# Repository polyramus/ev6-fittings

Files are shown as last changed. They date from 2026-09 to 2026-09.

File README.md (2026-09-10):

# ev6-fittings

*Ordning och reda* for the Kia EV6 — Swedish for “order and tidiness,” which is
the entire product line in one phrase.

3D-printed interior utility parts, one at a time. Each item fixes a small,
daily friction in the car that no official accessory covers. One subdirectory
per item; measured source data (STLs, photos) lives in `data/`.

## Items

### Cup-holder inlay (`cup-holder-inlay/`)

Drops into the center console cup holders:

- kills the rattle from the factory holder springs
- gives slim bottles a snug, non-rocking fit

### Planned

- Miniature trash can for the lower tray
- Replacement fuse box lid with an OBD-shaped opening

## Print notes

(to be filled in per item: printer, resin/PLA, orientation, supports)

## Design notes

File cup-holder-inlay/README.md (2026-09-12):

# Cup-holder inlay

Parametric OpenSCAD inlay for the EV6 centre-console cup area: immobilises the
four factory spring tabs (the rattle source) and adds a rattle-free grip for a
58 mm thermos or a 66 mm 0.5 l PET bottle in the front pocket.

## Files

- `ev6_cup_inlay.scad` — grip parameters, render switches, assembly, fit report
- `lib_geometry.scad` — all dimensional parameters + the three-tray envelope,
  conical front pocket, inlay shell, slanted console top
- `lib_parts.scad` — arc leaf-spring grip, factory-tab traps, test cups
- `aframe.scad` — the A-frame divider (see below), standalone part
- `lib_aframe.scad` — the A-frame divider: parameters + geometry, shared by
  `aframe.scad` (standalone) and the inlay assembly (fitted test object)
- `../data/` — the source data: `EV6 Utility Cup.stl`, `IMG_5344` (mat on a
  14" MBP, top view), `IMG_5345` (front pocket with the factory tabs),
  `IMG_5346` (console slant), `IMG_5347`/`IMG_5348` (mat + A-frame divider),
  `IMG_5349` (console from the passenger side; the driver-side A-stud),
  `IMG_5350` (mat + clamp on the floor, side view)

## Dimension provenance (2026-09-09, updated 2026-09-12)

- **Front pocket — precise (lower 62.5 mm).** `data/EV6 Utility Cup.stl`
  (Thingiverse, "EV6 Utility Cup (Precision Fit)") is a *negative* of the
  front cavity: conical, Ø75.07 at the seating level → Ø82.46 at its top,
  62.5 mm tall (walls lean out 3.7 mm/side). The part seats on the TPU mat.
  The pocket itself is taller (~79 mm from the mat to the console top — see
  the slant below), so the model continues the measured lean above the cone
  (`r_pocket`); the extra ~17 mm of wall is an assumption, flagged there.
- **Console top — slanted.** Caliper to the molded floor: 82 mm at the front,
  ~75 at the back; the TPU mat under the front pocket is ~3 mm, so the front
  pocket is ~79 from its floor (`H_FRONT_MAT`; if the caliper rested on the
  mat, set it to 82). With level floors (assumed) the top is one plane
  through (y=0, z=87) and (y=300.6, z=75) — `H_top(y)`, ~2.3°, falling to
  the rear. Everything is trimmed with `slant_cutter()`, so the inlay top is
  flush with the console top along the whole slant.
- **Rear footprint — photo.** `data/IMG_5344.jpg`: top view of the car's soft
  TPU mat on a 14" MacBook Pro (221.3 mm short side as scale). Total length
  298.9 mm, 24 mm passage, tab-notch pairs at both step corners, the 20×9 mm
  passenger-side bridge, and the long asymmetric tray-3 taper to a ~12 mm
  passenger tip (the LHD chamfer — the RHD variant is its mirror).
- **A-frame side profile + tenons — photo (2026-09-12).** `IMG_5350` (clamp
  side view) gives the asymmetric sawbuck contour; `IMG_5349` (console from
  the passenger side) gives the A-shaped floor tenons. The apex offset,
  dome radius, and tenon front-slant are read off the soft photo — caliper
  to confirm (see the A-frame section's assumed list).
- **Everything else** calipered by the owner. "width" = X (transverse),
  "length" = Y (fore-aft).

## Render

```sh
openscad -o inlay.png   -D 'TEST_CUP="none"'    ev6_cup_inlay.scad
openscad -o thermos.png -D 'TEST_CUP="thermos"' ev6_cup_inlay.scad
openscad -o pet.png     -D 'TEST_CUP="pet"'     ev6_cup_inlay.scad
```

`TEST_CUP` drops a translucent test cup into the front pocket and renders the
grip mechanism engaged against it. The compile-time `echo` report prints
pocket ID at seat/grip height, per-cup deflection, and the max arm strain.

## The factory-tab traps (measured 2026-09-10)

The four factory tabs are spring flaps 7.5 wide x 30 tall in wall openings:
pivot near the top, ~14 mm of free-end travel, folding fully into the wall
when pressed (which is exactly how the owner keeps them quiet). All four sit
~30 mm above their tray floor — the tray-2 pair level with the front pair.
(The white lines in photo `IMG_5345` are duct-tape residue from earlier
makeshift fastening, not damage.)

- **Front pocket** — two tabs ~45 deg each side of the passage (photo
  `IMG_5345`), on the cone. Traps are **flush-press bosses**: a tapered
  plate following the cone, its face 0.2 mm in front of the console wall
  face. The flap is trapped behind the inlay wall, so the face alone limits
  its bulge to 0.2 mm instead of 14 mm — no channel needed.
- **Tray 2** — two identical tabs at the tray-2/3 boundary (the mat notch
  pair, ~6 mm in from each wall, x = ±31.5), flaps tilted 45 deg toward each
  other — an X seen from above. No feature needed: the inlay's offset wall
  band runs full height over those faces, so the band's own face (0.15 mm
  in front of the car face) is the flush-press limiter. (First described
  against the 51-narrowing "step," since corrected to full width — re-confirm
  the exact face.)

Insertion: press all four tabs in, drop the inlay, and they stay
immobilised.

## The grip mechanism

Three arc-segment leaf-spring tabs (passenger, driver, front; the rear
quadrant is left clear for the trapped factory tabs). Each arm is an annular
sector following the pocket curvature, so nothing pokes through the circular
wall. The pad is printed 0.3 mm past its stop face, so in the car the arm is
pre-stressed and the pad is always pressed home — zero free play, and a hard
stop at the other end of travel (the cup), so it cannot rattle. PET
engagement bends the 1.2 mm arm ~4.6 mm over a 20 mm lever (~2 % strain —
at the low end of PLA/PETG yield).

## Print notes

- FDM, 0.2 mm layers, PETG preferred (arm flex + car heat).
- Print as-is (open top up): walls are vertical or leaning out, no supports
  needed; the grip pad bridges ~4 mm above the pocket floor (`GRIP_Z0`).
  The top rim is a slanted plane (the console slant) — cosmetic only.
- `TOL = 0.15` per side vs the car; drop to 0.1 if the fit feels loose.

## TODO — measurements still needed

Photo-derived values are soft-mat estimates (±3 mm); caliper to confirm:

- `H_FRONT_MAT` (79) — is the 82 mm caliper read to the molded floor (as
  assumed, minus the ~3 mm mat) or to the mat itself (then 82)? Also the
  ~17 mm of front-pocket wall above the measured STL cone assumes the lean
  continues — confirm the pocket's true top radius.
- `L_T2_CONN` (24), `L_T3_END_L` (50) / `L_T3_END_R` (20), `TIP_W` (12),
  `R_T3_CORNER` (6) — the rear end from the photo
- `BRIDGE_RELIEF` (1) — confirm the car's passage-1 bridge is flush with the
  mat top; set 0 if it sits below
- `GRIP_Z0` — land the grip band on the actual bottle's 66 mm body band
  (the test PET's 18 mm flare is a placeholder; measure the real bottle)
- The inlay seats on the TPU mat; if the mat compresses under the front
  section, the seat height shifts — verify in the car. The mat also has
  slightly raised sides extending ~1 mm past the base.

## The A-frame divider (`aframe.scad`)

The car's detachable A-frame divider, at the **tray-2 / tray-3 boundary**
in the rear console (not the front pocket). Its job is to stop the rattle
from the three loose plastic layers on the passenger-side console wall: the
inlay-fit variant below drops inside the printed inlay and cams that wall
ever so slightly outward on insertion, tensioning the cover. The factory
part is injection molded, but the shape prints fine in FDM.

**Shape (side profile, `IMG_5350`).** A **solid sawbuck** — an extruded "A"
with the counter filled, so the section is a solid triangle. It is
**asymmetric**, not a symmetric triangle: a long front slant, a short
near-vertical back, the apex offset toward the rear (~62% of the base,
`AFRAME_APEX_Y`), and a rounded top (`AFRAME_TOP_R`). 74 wide in X
(`AFR_CLAMP_W` — the tray walls are "almost 8 cm"), 45 deep in Y (the base),
61 tall in Z.

**The floor tenons (`IMG_5349`).** Two **A-shaped studs** rise ~1 cm from
the molded floor at the passage, one on each side (`AFR_STUD_*` in
`lib_geometry`): X-constant 11.75 wide, Y 34 → 30, the front face slanted
parallel to the frame's front slant and the back near-vertical. The frame
rests on their tops with the central passage left open (`AFR_PASSAGE_W`
= 50.5) — the "1 cm open area beneath the A-frame." No flange or latch; the
parallel front faces locate the frame. The tenons run from the passage all
the way to the console-well wall, so the inlay carries a matching
**A-shaped cutout** for each — through the floor *and* the side wall it
butts against (`aframe_stud_cutout` in `lib_aframe`).

**Bottle cutout.** A ~75 mm circle on one side (`CUTOUT_*`) so a bottle in
tray 2 sits in front of the frame; only its back crescent bites a ~45 mm
dent into the front slant.

**Two fits** (`AFRAME_FIT`; widths from `aframe_w`):
- **`"car"`** — the factory-style part: 74 wide, resting on the car's floor
  tenons (z = `AFR_STUD_H`), press-fitting the bare tray.
- **`"inlay"`** — the new divider: inset `AFR_INSET` (4) each side → 66
  wide, so it drops inside the inlay's rear void and cams the wall outward.
  Rendered in `ev6_cup_inlay.scad` with `SHOW_AFRAME=true`.

**Assumed, not measured** (flagged in the `lib_aframe.scad` header — verify
in the car): the frame's Y position (`AFRAME_Y0`), the apex offset + dome
radius (`AFRAME_APEX_Y` / `AFRAME_TOP_R`, read off the soft photo), the
bottle-cutout side/height/depth, and the tenon front-slant ratio.

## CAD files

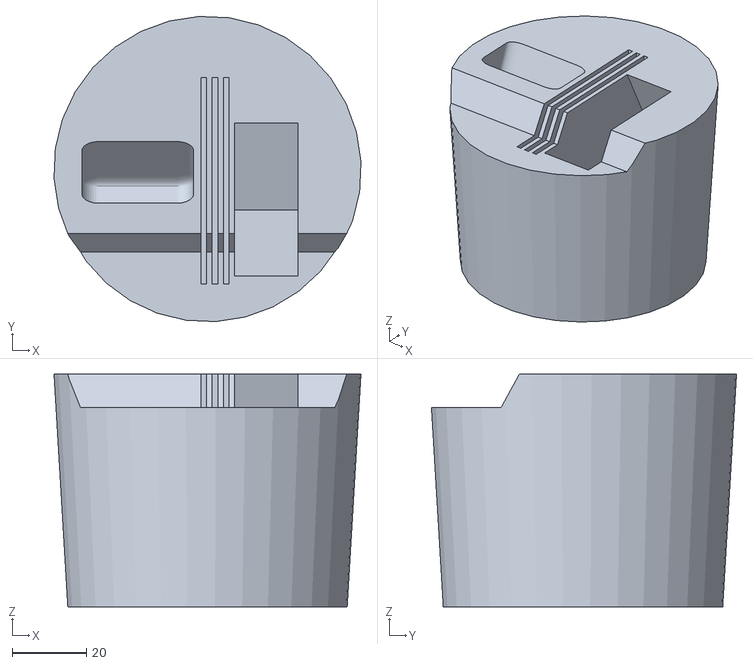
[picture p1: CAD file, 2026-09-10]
data/EV6 Utility Cup.stl
82.5 x 82.0 x 62.5

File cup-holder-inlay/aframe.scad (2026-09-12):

// aframe.scad — ev6-fittings / cup-holder-inlay
// Standalone preview of the A-frame divider. The geometry lives in
// lib_aframe.scad (shared with ev6_cup_inlay.scad, where the same frame also
// renders as a fitted test object inside the inlay); this file only picks a
// fit and renders it.
//
// The A-frame is a SOLID ASYMMETRIC SAWBUCK (an extruded "A" with the counter
// filled — long front slant, near-vertical back, apex toward the rear,
// rounded top): 74 wide in X (AFR_CLAMP_W, spans the tray), 45 deep in Y
// (the base), 61 tall in Z. It stands at the tray-2/tray-3 boundary on two
// A-shaped floor tenons; a circular cutout on one side lets a bottle sit in
// tray 2. See lib_aframe for the dimensions and the ASSUMED list (verify in
// the car).
//
// Fit (AFRAME_FIT):
//   "car"   — the factory-style part: 74 wide, resting on the car's floor
//             tenons (z = AFR_STUD_H), press-fitting the bare car tray.
//   "inlay" — the NEW slightly-smaller divider: fits inside the printed
//             inlay's tray-2/3 void and pushes the inlay wall outward to
//             strain the console.
//
// Render:
//   openscad -o aframe.png        aframe.scad                 // inlay fit, inlay shown
//   openscad -o aframe_car.png    -D 'AFRAME_FIT="car"' -D 'SHOW_INLAY=false' aframe.scad
//   (add -D 'SHOW_POCKET=true' to ghost the car cavity)

$fn = 96;
include <lib_geometry.scad>   // TOL, WALL, inlay_shell, cavity, tray-2/3 Y layout
include <lib_aframe.scad>     // aframe(fit), aframe_solid, aframe_z0

AFRAME_FIT   = "inlay";   // "car" | "inlay"
SHOW_POCKET  = false;     // ghost the car cavity
SHOW_INLAY   = true;      // the printed inlay the "inlay" fit lives inside

if (SHOW_POCKET)
    color("gray", 0.25) cavity();
if (SHOW_INLAY)
    color("#d8d8d0", 0.35) inlay_shell();
color("#b0b0a8") aframe(AFRAME_FIT);

echo("aframe (", AFRAME_FIT, "): ", aframe_w(AFRAME_FIT), " x 61 x 45 sawbuck, y0 ", AFRAME_Y0,
     ", z0 ", aframe_z0(AFRAME_FIT));

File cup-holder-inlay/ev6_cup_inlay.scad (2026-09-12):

// ev6_cup_inlay.scad — ev6-fittings
// Parametric inlay for the Kia EV6 centre-console cup area (3 interconnected
// trays). Goals:
//   1. immobilise the four factory spring tabs (rattle source)
//   2. rattle-free grip for 58 mm thermos ... 66 mm 0.5 l PET in the front
//      pocket (leaf-spring tabs, both travel ends hard-stopped)
//   3. fill/flatten the remaining two trays
//
// OpenSCAD >= 2021.  Render the three fits:
//   openscad -o inlay.png      -D 'TEST_CUP="none"'    ev6_cup_inlay.scad
//   openscad -o thermos.png    -D 'TEST_CUP="thermos"' ev6_cup_inlay.scad
//   openscad -o pet.png        -D 'TEST_CUP="pet"'     ev6_cup_inlay.scad
//   openscad -o aframe_fit.png -D 'TEST_CUP="none"' -D 'SHOW_AFRAME=true' \
//                              ev6_cup_inlay.scad      // A-frame clamp in the inlay
//   (add -D 'SHOW_ENVELOPE=true' to ghost the car cavity around the inlay)
//
// Dimension provenance lives with the dimensions, in lib_geometry.scad
// (STL + top-view photo, 2026-09-09). This file keeps the grip mechanism
// parameters, the render switches, the assembly and the fit report.
//
// Coordinate system: X transverse, +X = driver side (LHD), -X = passenger;
// Y fore-aft, +Y toward the rear trays; z=0 = lower (rear) tray floor,
// z=LIFT = front pocket floor, z=H_top(y) = slanted console top.

// ================= grip mechanism =================
// Arc-segment leaf-spring tabs (see lib_parts.scad): the arm is an annular
// sector following the pocket curvature, so every feature stays inside the
// pocket; deflection is an exact rotation about the pocket centre.
CUP_MIN_D  = 58.0;   // thermos
CUP_MAX_D  = 66.0;   // 0.5 l PET body (EU standard max)
GRIP_TAB_ANG = [0, 180, 270];  // rear quadrant left clear for factory tabs
GRIP_SPAN    = 36.0;   // arm arc span (deg); lever ~ r * span = 20 mm
GRIP_ARM_R0  = 32.0;   // arm inner radius (centreline 32.6)
GRIP_ARM_T   = 1.2;    // arm radial thickness = bending direction
PRELOAD      = 0.3;    // print the pad 0.3 mm PAST the stop face: in the car
                       // the stop blocks it, so the arm is pre-stressed and
                       // the pad is always pressed home -> zero free play
GRIP_Z0      = 4.0;    // TODO: grip band bottom above pocket floor; keep the
GRIP_Z_H     = 10.0;   // pad's bottom bridge short (FDM), land on the PET
                       // 66 mm body band

// ================= render switches =================
TEST_CUP      = "thermos";  // "none" | "thermos" | "pet"
SHOW_ENVELOPE = false;
// A-frame divider fitted inside the inlay's rear (tray-2/3) void (the "inlay"
// fit from lib_aframe — the slightly-smaller clamp that cams the wall out).
// Render it alone (TEST_CUP="none"): the inlay goes translucent so the frame
// inside the rear void reads.
SHOW_AFRAME   = false;

// High-poly circles (kit convention, cf. motor-bench/cad/params.scad): the
// 74 mm pocket circle runs through offset() and CSG booleans.
$fn = 96;

include <lib_geometry.scad>
include <lib_parts.scad>
include <lib_aframe.scad>   // the A-frame divider, rendered as a fitted test object

// ================= assembly =================
// defl: render the grip arms deflected outward from the printed (empty)
// state -- 0 for a bare inlay, cup_deflection(d) to show a cup engaged.
module inlay(defl = 0) {
    union() {
        inlay_shell();
        grip_tabs(defl);
        factory_tab_bosses();   // flush-press bosses; no channels — the
                                // flaps fold behind the inlay wall (lib_parts)
    }
}

module assembly() {
    defl = TEST_CUP == "pet" ? cup_deflection(CUP_MAX_D)
           : TEST_CUP == "thermos" ? cup_deflection(CUP_MIN_D)
           : 0;
    if (SHOW_ENVELOPE) cavity_ghost();
    // Translucent inlay while the A-frame test object is inside, so the
    // band-vs-wall fit reads; the cup renders stay opaque.
    color("#b8b8b0", SHOW_AFRAME ? 0.3 : 1.0) inlay(defl);
    if (TEST_CUP != "none") test_cups();
    if (SHOW_AFRAME) color("#8a8a80") aframe("inlay");
}

assembly();

// ================= clearance / fit report =================
echo("console top: front = ", H_TOP_FRONT, " mm, rear = ", H_top(Y_T3_REAR),
     " mm, slant = ", SLANT_ANG, " deg");
echo("front pocket ID @ seat = ", 2 * (R_T1_BOT - TOL - WALL),
     " mm (STL cavity 75.07)");
echo("front pocket ID @ top  = ", 2 * (r_pocket(H_TOP_FRONT) - TOL - WALL),
     " mm (lean continued past the STL cone, see H_FRONT_MAT)");
echo("front pocket ID @ grip = ", 2 * R_PKT_GRIP, " mm (z = ", GRIP_ZC, ")");
echo("thermos radial play    = ", R_PKT_GRIP - CUP_MIN_D / 2,
     " mm/side at the grip band (closed by the pads)");
echo("PET body radial play   = ", R_PKT_GRIP - CUP_MAX_D / 2,
     " mm/side at the grip band (closed by the pads)");
echo("pad face: printed/seated = ", PAD_PRINT_R, " / ", PAD_STOP_R, " mm");
echo("thermos arm deflection = ", cup_deflection(CUP_MIN_D), " mm over L=", GRIP_LEVER);
echo("PET arm deflection     = ", cup_deflection(CUP_MAX_D), " mm over L=", GRIP_LEVER);
echo("max arm strain ~       = ", 3 * cup_deflection(CUP_MAX_D) * GRIP_ARM_T / (2 * GRIP_LEVER^2),
     " (yield ~0.02-0.05 for PLA/PETG)");
echo("total footprint length = ", Y_T3_REAR,
     " mm (front edge to passenger tip; photo read 298.9)");

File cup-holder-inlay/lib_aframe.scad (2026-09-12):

// lib_aframe.scad — ev6-fittings / cup-holder-inlay
// The A-frame divider: parameters + geometry, shared by the standalone
// preview (aframe.scad) and the inlay assembly (ev6_cup_inlay.scad, where
// it renders as a fitted test object).
//
// What it is (user 2026-09-10; contour from IMG_5350, tenons from IMG_5349,
// 2026-09-12): a SOLID SAWBUCK — an extruded "A" with the counter filled, so
// the section is a solid ASYMMETRIC triangle (long front slant, short
// near-vertical back, apex offset toward the rear, rounded top — see
// aframe_section). It stands at the tray-2/tray-3 boundary in the rear
// console: 74 wide in X (AFR_CLAMP_W, spans the tray), 45 deep in Y (the
// base), 61 tall in Z. A circular cutout on one side lets a bottle sit in
// tray 2. It rests on two A-shaped floor tenons (aframe_tenons). The factory
// part is injection molded; the shape prints fine in FDM.
//
// Requires lib_geometry.scad to be included first (TOL, WALL, and the
// tray-2/3 Y layout: Y_T2_REAR, Y_P2_REAR). No top-level instantiation here.
//
// ================= ASSUMED — verify in the car =================
//   AFRAME_Y0  — where it sits in Y. Set to the tray-2/3 boundary (Y_T2_REAR,
//                y~188). The 45 base then runs from there toward tray 3.
//                Confirm the exact position in the car.
//   AFRAME_APEX_Y / AFRAME_TOP_R — apex offset toward the rear + rounded-top
//                radius, read off IMG_5350 (a soft, angled photo). Caliper.
//   CUTOUT_*   — the ~75 mm bottle circle: placed in front (toward tray 2),
//                centred on x=0, so only its back crescent bites a ~45 mm-wide,
//                9-10 mm-deep dent into the front slant. Confirm which side it
//                is actually on and the exact height/depth in the car.
// ================================================================

// ---- envelope (measured 2026-09-10) ----
AFRAME_BASE = 45.0;   // base depth (Y), the "45 at the base"
AFRAME_H    = 61.0;   // total height (Z), the "~6 cm tall"
// Side profile (IMG_5350): ASYMMETRIC. A long front slant, a short near-
// vertical back, apex offset toward the rear, rounded top. APEX_Y is the
// apex's offset from the front edge along the base (middle = BASE/2).
AFRAME_APEX_Y = 28.0;    // apex toward the back (~62% of the base)
AFRAME_TOP_R  = 6.0;     // rounded-top radius
// (width is aframe_w(fit) -> AFR_CLAMP_W = 74, the clamp spanning the ~79
//  tray; user 2026-09-10: "the walls are always at almost 8 cm".)
// The A-frame sits at the tray-2/3 boundary (y 188..225 in lib_geometry);
// its 45 base spans that region. Two floor tenons protrude here and the frame
// rests on them (see aframe_tenons). The base is raised AFR_STUD_H above the
// floor, leaving the passage open in the middle.
AFRAME_Y0   = 184.0;  // 45 base centred on passage 2 (188..225), bridging it

// ---- bottle cutout (user 2026-09-10) ----
// A ~75 mm circle (a bottle sitting in tray 2) that only CLIPS the front of
// the frame: its back crescent bites a ~45 mm-wide, 9-10 mm-deep dent into the
// front slant. It is NOT a through-hole -- the circle mostly sits in tray 2.
CUTOUT_D  = 75.0;         // the bottle circle diameter (user "~75 mm")
CUTOUT_CY = AFRAME_Y0 - 28.0;  // ASSUMED circle centre (x=0, in front of the
                               // base edge): 37.5-28 = 9.5 mm of crescent bites
                               // in (~45-50 mm wide). Confirm side + position.

// ---- fit ----
// "car":   the factory part — AFR_CLAMP_W (74) wide, press-fitting the bare
//          car tray; rests on the car's floor tenons (z = AFR_STUD_H).
// "inlay": the NEW divider — inset AFR_INSET each side so it fits inside the
//          inlay's rear void and cams the wall outward on insertion. The inlay
//          void is the car footprint (75->71) offset in by WALL+TOL, ~67-71.
// Both rest ON the two A-shaped floor tenons: the base sits at the tenon tops,
// AFR_STUD_H above the car floor, in EITHER fit (the tenons rise from the car
// floor to z=AFR_STUD_H whether or not the inlay is present — through the
// inlay floor for the inlay fit). The ~1 cm void beneath is open in the
// middle (the passage), tenons on the sides.
AFR_INSET = 4.0;   // inlay-fit inset each side (fits the inlay rear void,
                   // tightest at the tray-3 side ~66.5 mm)
function aframe_w(fit) = fit == "inlay" ? AFR_CLAMP_W - 2 * AFR_INSET : AFR_CLAMP_W;
function aframe_z0(fit) = AFR_STUD_H;

// Solid-sawbuck section as a 2D profile (local x = height/Z, local y = Y):
// an ASYMMETRIC triangle (IMG_5350) — front-base [0,0], back-base [0,BASE],
// apex toward the rear at [h-R, APEX_Y] — with a rounded top: the hull of the
// triangle and a TOP_R circle at the apex gives straight slants + a dome.
module aframe_section(h) {
    hull() {
        polygon(points = [
            [0, 0],
            [0, AFRAME_BASE],
            [h - AFRAME_TOP_R, AFRAME_APEX_Y],
        ]);
        translate([h - AFRAME_TOP_R, AFRAME_APEX_Y])
            circle(d = 2 * AFRAME_TOP_R);
    }
}

// The solid sawbuck, aframe_w(fit) across (X). Rotate -90 about Y maps local
// z -> global -x and local x -> global z, so the extrude runs -X: origin at
// +w/2, base at AFRAME_Y0, floor at aframe_z0(fit).
module aframe_solid(fit) {
    w = aframe_w(fit);
    translate([w / 2, AFRAME_Y0, aframe_z0(fit)])
        rotate([0, -90, 0])
            linear_extrude(w) aframe_section(AFRAME_H);
}

module aframe(fit = "car") {
    difference() {
        aframe_solid(fit);
        // the bottle dent: a 75 mm vertical cylinder centred in front of the
        // base edge (toward tray 2) -- only its back crescent removes material
        translate([0, CUTOUT_CY, aframe_z0(fit) - 1])
            cylinder(h = AFRAME_H + 2, d = CUTOUT_D);
    }
}

// ---- floor tenons (the CAR feature the frame drops onto) ----
// Two A-shaped tenons at the passage (lib_geometry AFR_STUD_*): X width
// constant, ~1 cm tall, Y-footprint AFR_STUD_L_BASE at the floor narrowing to
// AFR_STUD_L_TOP at the top. The FRONT face slants back parallel to the frame's
// front slant (the "slant that matches the inside of the a-frame", IMG_5349)
// and the back face is near-vertical — so each tenon is a small positive "A".
// No flange/latch — the clamp rests on the tops and the parallel front faces
// locate it. Rendered as reference car geometry (aframe.scad), NOT part of the
// printable frame.
module aframe_stud_section() {
    // 2D profile (local x = height/Z, local y = Y-depth, front = 0). Base
    // L_BASE (front y=0 .. back y=L_BASE), front face slants back to L_TOP at
    // the top, back face vertical.
    polygon(points = [
        [0, 0],                                       // front-bottom
        [0, AFR_STUD_L_BASE],                         // back-bottom
        [AFR_STUD_H, AFR_STUD_L_BASE],                // back-top (back vertical)
        [AFR_STUD_H, AFR_STUD_L_BASE - AFR_STUD_L_TOP], // front-top (front slant)
    ]);
}
module aframe_tenon(sx) {
    cx = sx * AFR_STUD_X;
    translate([cx + AFR_STUD_W / 2, AFR_STUD_Y - AFR_STUD_L_BASE / 2, 0])
        rotate([0, -90, 0])
            linear_extrude(AFR_STUD_W) aframe_stud_section();
}
module aframe_tenons() {
    aframe_tenon(-1);
    aframe_tenon(1);
}

// A-shaped clearance cutout for one floor tenon, subtracted from the inlay
// (lib_geometry.inlay_shell). The tenons run from the passage ALL THE WAY to
// the console-well wall, so the cutout is the tenon's A-profile offset out by
// TOL, extruded from the passage edge across to past the wall — clearing the
// tenon through BOTH the inlay floor and the side wall it butts against.
module aframe_stud_cutout(sx) {
    x0 = AFR_PASSAGE_W / 2;          // passage edge
    x1 = AFR_CLAMP_W / 2 + 1;        // past the wall (clipped by the shell)
    tx = sx > 0 ? x1 : -x0;          // extrude origin on the wall side
    translate([tx, AFR_STUD_Y - AFR_STUD_L_BASE / 2, 0])
        rotate([0, -90, 0])
            linear_extrude(x1 - x0)
                offset(TOL) aframe_stud_section();
}

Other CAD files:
cup-holder-inlay/lib_geometry.scad
cup-holder-inlay/lib_parts.scad

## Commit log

2026-09-09 Cup-holder inlay: parametric OpenSCAD draft
    Three-tray console envelope from calipered dimensions (74 mm front pocket,
    8 mm step, 24/51 mm passages, tray 2 expansion, tray 3 taper+rounded end).
    Arc leaf-spring grip for 58-66 mm cups with preloaded hard stops (rattle-
    free), factory spring-tab traps, and translucent test-cup render cases.
    Unmeasured dimensions are flagged TODO in the parameter block.
    [ev6_cup_inlay.scad, lib_geometry.scad, lib_parts.scad]
2026-09-10 Cup inlay: conical front pocket from STL data, LHD tray-3 end, photo-derived rear layout
    Front section rebuilt from the Thingiverse 'EV6 Utility Cup (Precision
    Fit)' STL (a negative of the front cavity): cone 75.07 -> 82.46 over
    62.5 mm, so the walls lean out 3.7 mm/side; H_DEPTH resolved to 70.5
    (8 mm step + 62.5). Rear footprint from the top-view photo of the TPU
    mat (14-inch MBP as scale): 299 mm total, LHD tray-3 end (long
    chamfered passenger tip, short driver end - the earlier draft was the
    RHD mirror), tab-notch pairs at both step corners, 20x9 mm
    passenger-side bridge with a 1 mm floor relief. Grip radii now follow
    the cone via r_pocket(z); the two curved factory-tab traps follow the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
    [EV6 Utility Cup.stl, ev6_cup_inlay.scad, lib_geometry.scad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]
2026-09-10 Tab traps: measured geometry, flush-press design
    Owner measurements 2026-09-10 (photos IMG_5345-5348): the factory tabs
    are 7.5 x 30 spring flaps in wall openings, ~14 mm travel, pivot near
    the top, folding fully into the wall; the front-pocket pair sits ~45 deg
    each side of the passage and both are broken at the tip (the rattle
    source).
    The front-pocket traps become flush-press bosses: tapered plates
    following the cone, face 0.2 mm in front of the console wall face, so a
    folded flap can only bulge 0.2 mm instead of 14 mm. No channel is cut in
    the inlay for these; the flap is trapped behind the inlay wall. Verified
    with a containment test against the car-cavity envelope (nothing exceeds
    it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
    [lib_geometry.scad, lib_parts.scad]
2026-09-10 Slanted console top, resolved tab data, tray-2 traps simplified
    - Model the visible console slant: plane through (front 87, rear 75),
    ~2.3 deg, from the owner's 82/75 caliper reads (mat ~3 mm, level
    floors assumed). Inlay + cavity trimmed with slant_cutter(); the inlay
    top is flush with the console top along the whole slant.
    - Front-pocket wall above the measured STL cone: the lean is assumed to
    continue (~17 mm extra); flagged as H_FRONT_MAT with a 79/82 knob.
    - TAB1_Z0 = 30 (owner gauge); the "broken at the tip" note was wrong —
    the white lines in IMG_5345 are duct-tape residue.
    - Tray-2 tabs sit on the 75->51 step faces (mat notch pair, 6 mm in from
    each passage-2 wall), 38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
    [ev6_cup_inlay.scad, lib_geometry.scad, lib_parts.scad]
2026-09-10 Model the A-frame divider (aframe.scad)
    Printable replacement for the factory A-frame: an arch (two legs 45
    apart in Y, web, rounded r22.5 top) 61 tall, extruded 79 across the
    pocket with the outer face trimmed to the cone (r_pocket - TOL) so the
    band hugs it. Two inside C-hook supports at 50.5 (factory 50 + the
    owner's 0.5 shims) clamp the two floor studs; pressing down cams the
    cone fit and tensions the three-layer passenger-side cover.
    Envelope (79 x 61 x 45, rounded 22 top, 50.5 supports) is measured;
    the in-pocket Y position, cutout size/height, stud centreline/diameter
    and leg thickness are flagged ASSUMED in the header. Containment
    against the car cavity is clean.
    One open contradic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
    [aframe.scad]
2026-09-10 A-frame: fitted test object + slightly-smaller inlay-fit clamp
    The A-frame divider now renders as a test object inside the inlay
    (SHOW_AFRAME in ev6_cup_inlay.scad, inlay goes translucent) and as a
    standalone preview (aframe.scad, AFRAME_FIT switch). The shared geometry
    moved to lib_aframe.scad, included by both.
    New "inlay" fit: the frame stands on the inlay floor and its band sits
    AFRAME_CLEAR inside the inlay's void wall -- positive = slip fit, negative
    = press fit (wedges in and pushes the inlay wall out to strain the console
    shell). "car" fit is the factory-style part in the bare pocket.
    lib_geometry: floor-stud interface (STUD_*) + STUD_HOLES open the inlay
    floor so the C-hooks reach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
    [aframe.scad, ev6_cup_inlay.scad, lib_aframe.scad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]
2026-09-11 A-frame: rebuild to the real sawbuck + floor tenons
    The A-frame was modeled as a front-pocket tombstone; the part is actually a
    solid sawbuck (filled-A) at the tray-2/3 boundary, 74 wide (X) x 45 base (Y)
    x 61 tall (Z), with a 75 mm bottle-dent crescent on the front face.
    - lib_aframe: sawbuck section corrected (base along Y, apex up); base raised
    AFR_STUD_H above the floor; aframe_tenon()/aframe_tenons() for the two
    rectangular floor tenons (X-constant, Y narrowing up, ~1 cm tall) that the
    frame rests on, leaving the passage open in the middle.
    - lib_geometry: replace the stale front-pocket STUD_* with the measured
    AFR_STUD_* (clamp 74 / passage 50.5 / tenon ~11.75 X, Y 34->30, 1 c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
    [aframe.scad, lib_aframe.scad, lib_geometry.scad]
2026-09-11 A-frame: fix rear width, add the inlay-fit variant
    User confirmed the rear tray is full-width at the A-frame's Y, not the
    51 mm narrowing the top-view photo suggested. Reworked rear_footprint so
    passage-2 is a continuous 75->71 trapezoid (P2_W removed); the inlay's
    rear void is now ~67-71 mm.
    - lib_aframe: aframe_w(fit)/AFR_INSET give the inlay-fit a 66 mm body
    (inset 4 mm/side) that drops inside the inlay rear void; aframe_z0 is
    AFR_STUD_H for both fits since the tenons set the base height either
    way. Dropped the now-unused AFRAME_W.
    - lib_geometry: rear tenon clearance holes so the car's floor tenons rise
    through the inlay floor for the inlay-fit.
    Renders confirm the inlay-fit fr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
    [lib_aframe.scad, lib_geometry.scad]
2026-09-12 A-frame: asymmetric contour + A-shaped floor tenons
    Match the two new side photos (2026-09-12, IMG_5349/5350):
    - Side contour (IMG_5350): the sawbuck is ASYMMETRIC, not a symmetric
    triangle — a long front slant, a short near-vertical back, apex offset
    toward the rear (~62% of the base), rounded top. New AFRAME_APEX_Y /
    AFRAME_TOP_R; aframe_section() is now the hull of the triangle and an
    apex circle (straight slants + dome).
    - Floor tenons (IMG_5349): the driver/passenger studs are small positive
    "A"s, not symmetric frustums. Front face slants back parallel to the
    frame's front slant (the "slant that matches the inside of the a-frame"),
    back face near-vertical, X-constant 11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
    [lib_aframe.scad]
2026-09-12 Docs: reconcile the A-frame + tenon descriptions with the current model
    The README A-frame section and several file headers still described the
    abandoned first draft (front-pocket arch with two legs + web, r=22.5
    semicircle top, cone press-fit, 79 wide, 50 mm studs). Reconcile to what is
    actually modeled:
    - README A-frame section: full rewrite — solid ASYMMETRIC sawbuck at the
    tray-2/3 boundary (74 wide), A-shaped floor tenons, bottle cutout, and the
    car/inlay fits.
    - Add lib_aframe.scad to the Files list (it was missing) and IMG_5349/5350
    to the provenance.
    - lib_aframe / aframe headers: 79 -> 74, describe the asymmetric profile +
    A-tenons, car fit rests on the tenons (z=AFR_STUD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
    [aframe.scad, ev6_cup_inlay.scad, lib_aframe.scad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]
2026-09-12 Inlay: A-shaped tenon cutouts through the floor AND side wall
    The floor tenons run from the passage all the way to the console-well wall
    (user 2026-09-12), so the inlay needs an A-shaped cutout for each — not just
    in the floor but in the side wall the tenon butts against too.
    - lib_aframe: new aframe_stud_cutout(sx) — the tenon's A-profile offset out
    by TOL, extruded from the passage edge across to past the wall.
    - lib_geometry.inlay_shell: replace the old rectangular floor-clearance box
    with aframe_stud_cutout(-1/1), so the inlay-fit frame can rest on the
    tenons and the tenons clear the wall they reach. (Cross-include: the
    rear section now calls into lib_aframe.)
    - README: note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
    [lib_aframe.scad, lib_geometry.scad]
